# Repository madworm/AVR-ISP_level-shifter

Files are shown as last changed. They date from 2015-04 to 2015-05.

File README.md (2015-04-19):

AVR-ISP_level-shifter
=====================

LAYOUT FILES: Bidirectional level-shifter for old 5V-only AVR-ISP programmers
	      (or for ones that claim to do 3.3V and only offer that on VCC - not on I/O).

---

Before having PC-boards made, please make sure you know about your manufacturer's peculiarities!
Especially drill-sizes and their tolerances may vary too much and give you trouble.

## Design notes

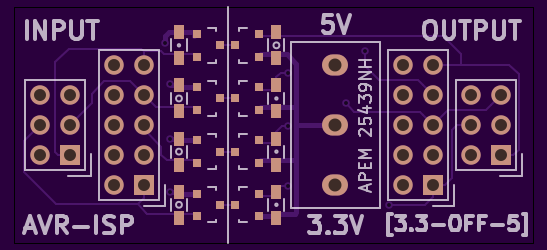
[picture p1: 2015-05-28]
gerber_files/PNGs/AVR-ISP_level-shifter__front_purple.png

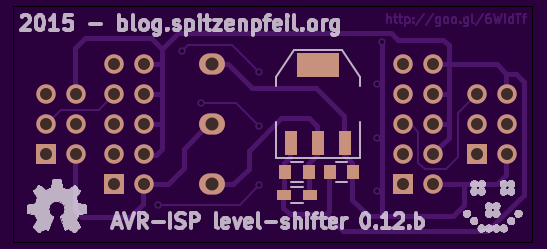
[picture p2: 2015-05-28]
gerber_files/PNGs/AVR-ISP_level-shifter__back_purple.png

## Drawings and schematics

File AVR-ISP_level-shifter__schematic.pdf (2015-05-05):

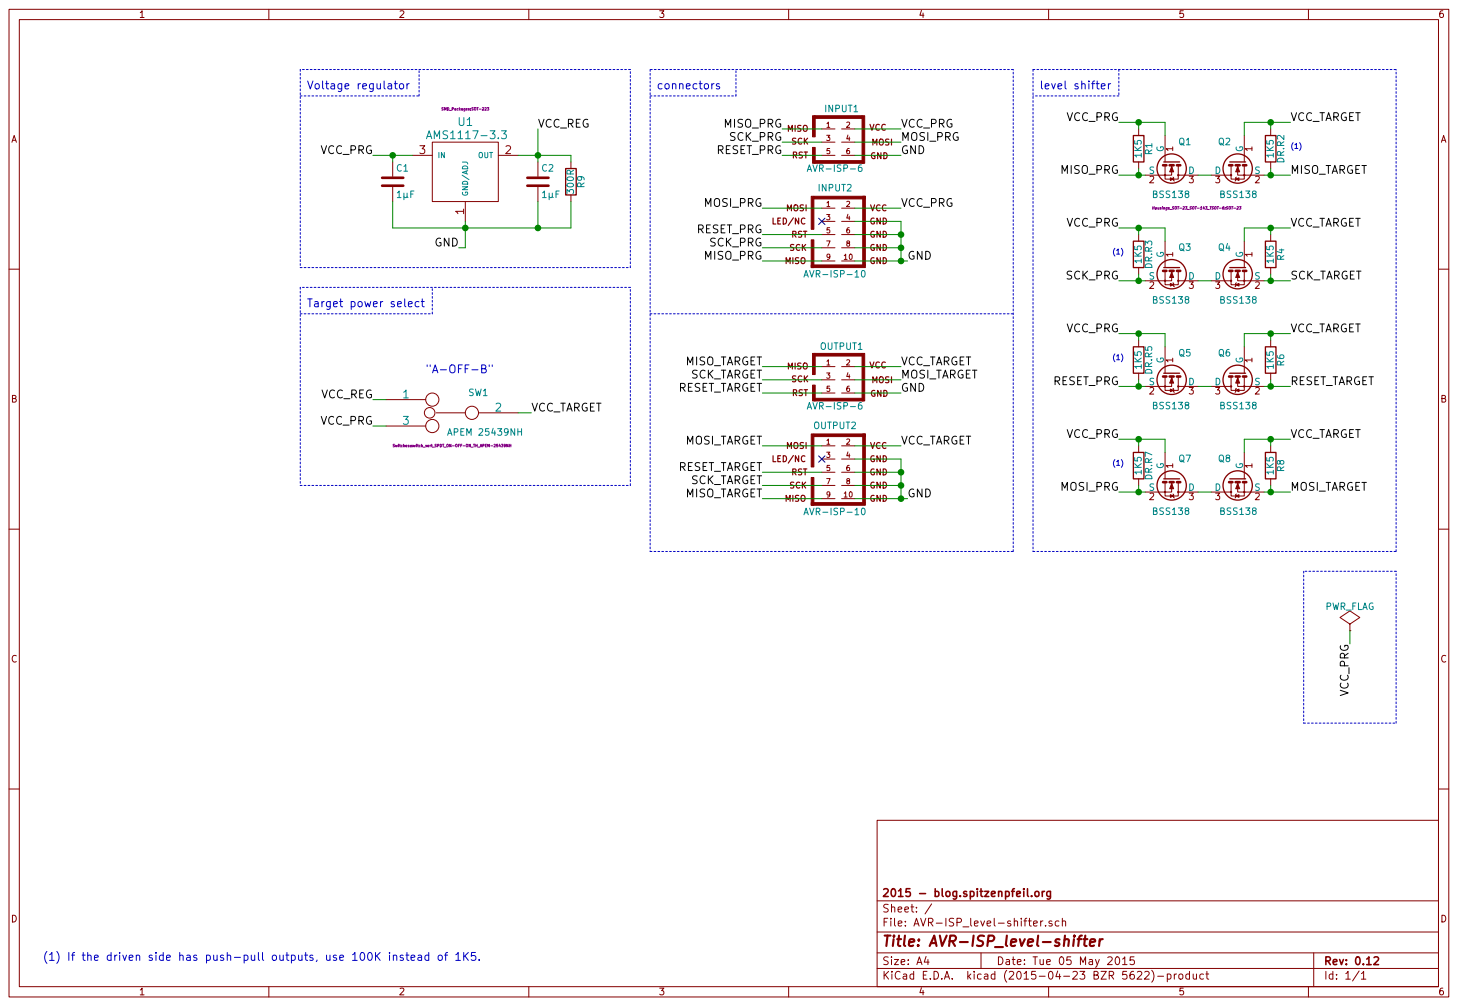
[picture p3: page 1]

File: AVR-ISP_level-shifter.sch Sheet: / 2015 - blog.spitzenpfeil.org GND/ADJ 1

VCC_PRG
VCC GND GND GND

VCC_TARGET

Id: 1/1 Title: AVR-ISP_level-shifter

(1) If the driven side has push-pull outputs, use 100K instead of 1K5.

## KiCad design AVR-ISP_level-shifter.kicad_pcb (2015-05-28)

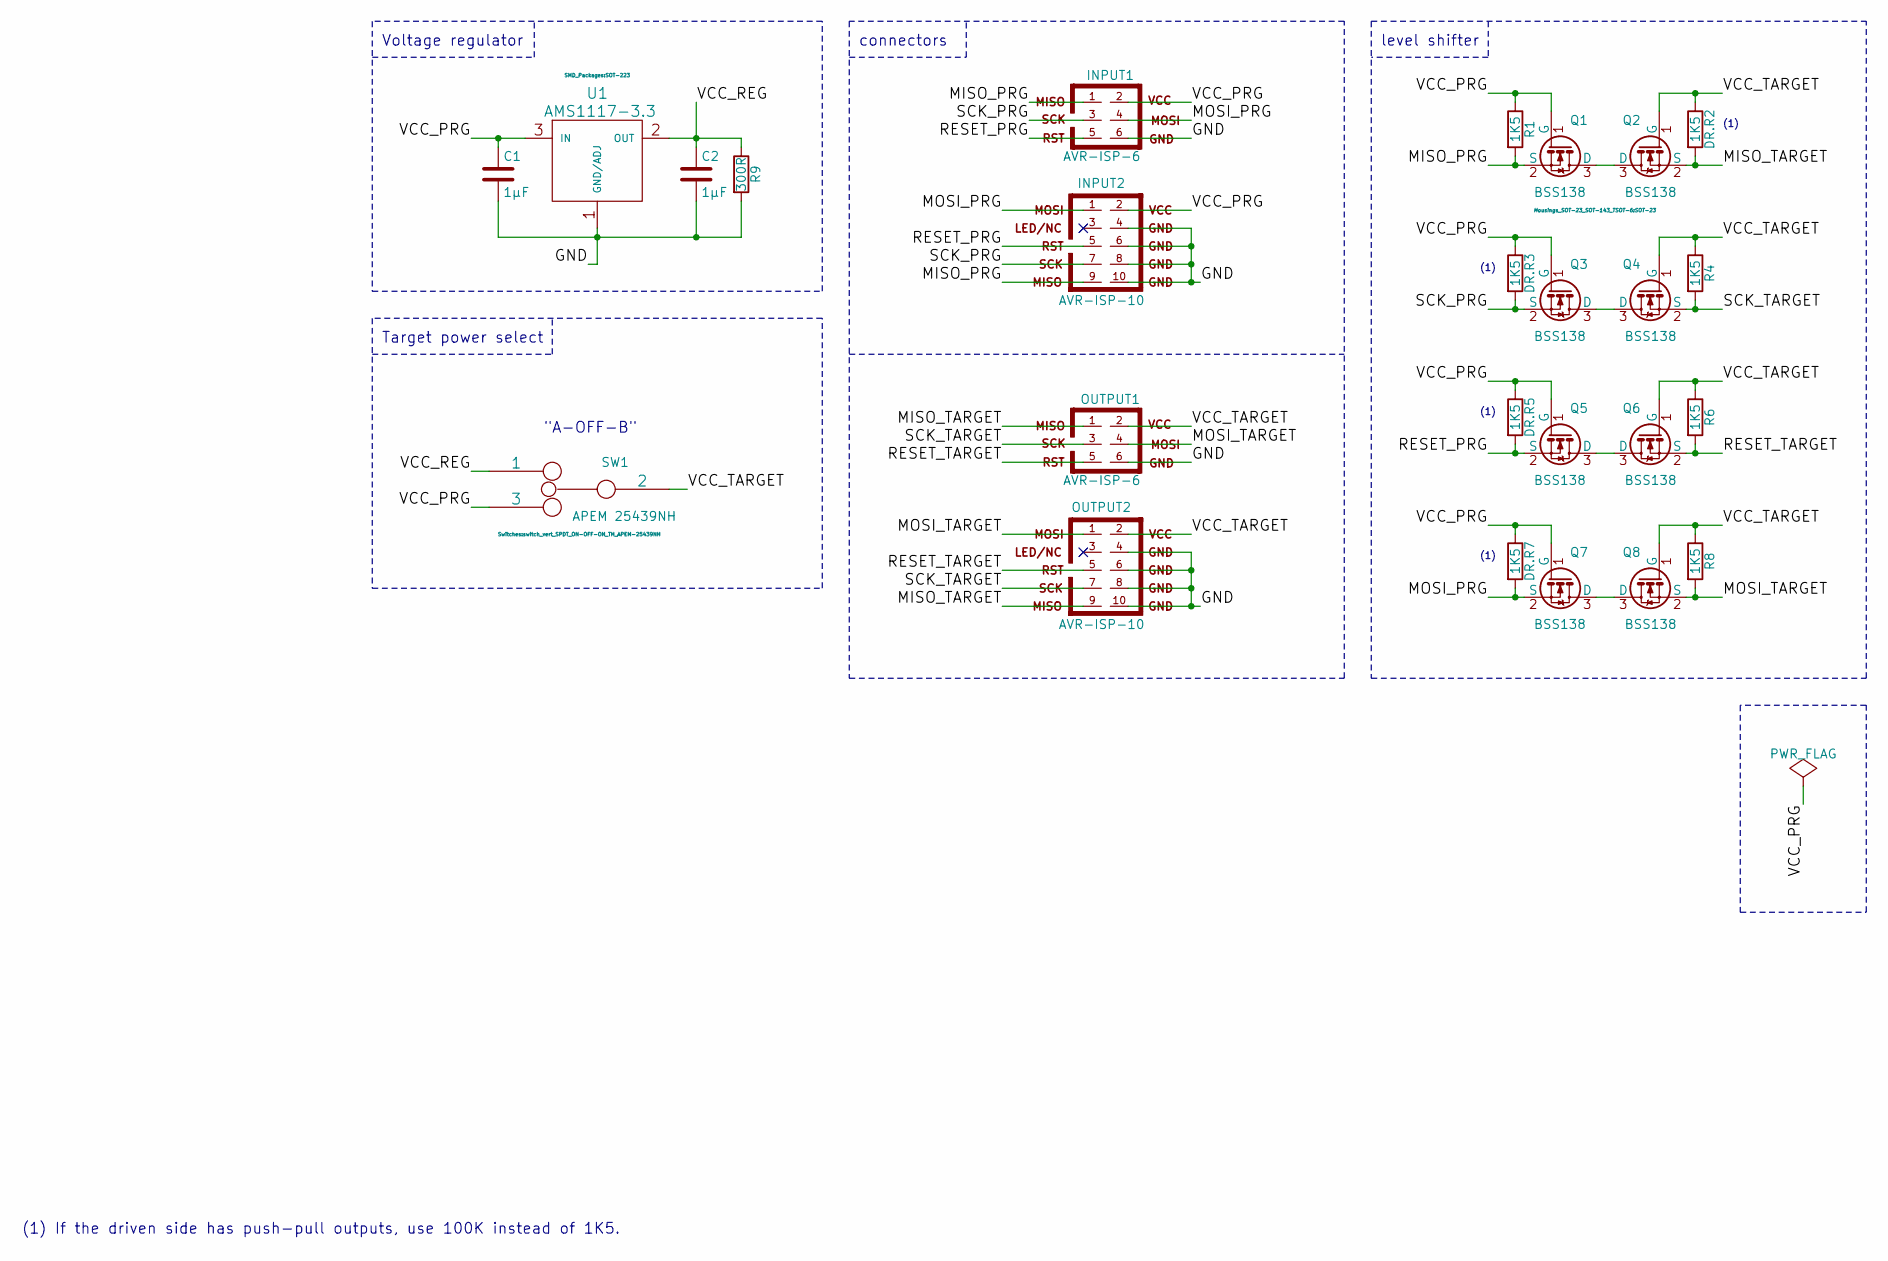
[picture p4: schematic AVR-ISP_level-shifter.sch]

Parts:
C1, C2: 1µF; C_0805
DR.R2, DR.R3, DR.R5, DR.R7: 1K5; R_0603_HandSoldering
INPUT1: AVR-ISP-6; DIL-3
INPUT2: AVR-ISP-10; DIL-5
OUTPUT1: AVR-ISP-6; DIL-3
OUTPUT2: AVR-ISP-10; DIL-5
Q1, Q2, Q3, Q4, Q5, Q6, Q7, Q8: BSS138; SOT-23
R1, R4, R6, R8: 1K5; R_0603_HandSoldering
R9: 300R; R_0603_HandSoldering
SW1: APEM 25439NH; switch_vert_SPDT_ON-OFF-ON_TH_APEM-25439NH
U1: AMS1117-3.3; SOT-223

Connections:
/GND: C1.2, C2.2, INPUT1.6, INPUT2.4, INPUT2.6, INPUT2.8, INPUT2.10, OUTPUT1.6, OUTPUT2.4, OUTPUT2.6, OUTPUT2.8, OUTPUT2.10, R9.2, U1.1 (GND/ADJ)
/MISO_PRG: INPUT1.1, INPUT2.9, Q1.2 (S), R1.2
/MISO_TARGET: DR.R2.2, OUTPUT1.1, OUTPUT2.9, Q2.2 (S)
/MOSI_PRG: DR.R7.2, INPUT1.4, INPUT2.1, Q7.2 (S)
/MOSI_TARGET: OUTPUT1.4, OUTPUT2.1, Q8.2 (S), R8.2
/RESET_PRG: DR.R5.2, INPUT1.5, INPUT2.5, Q5.2 (S)
/RESET_TARGET: OUTPUT1.5, OUTPUT2.5, Q6.2 (S), R6.2
/SCK_PRG: DR.R3.2, INPUT1.3, INPUT2.7, Q3.2 (S)
/SCK_TARGET: OUTPUT1.3, OUTPUT2.7, Q4.2 (S), R4.2
/VCC_PRG: C1.1, DR.R3.1, DR.R5.1, DR.R7.1, INPUT1.2, INPUT2.2, Q1.1 (G), Q3.1 (G), Q5.1 (G), Q7.1 (G), R1.1, SW1.3, U1.3 (IN)
/VCC_REG: C2.1, R9.1, SW1.1, U1.2 (OUT)
/VCC_TARGET: DR.R2.1, OUTPUT1.2, OUTPUT2.2, Q2.1 (G), Q4.1 (G), Q6.1 (G), Q8.1 (G), R4.1, R6.1, R8.1, SW1.2
unnamed: Q1.3 (D), Q2.3 (D)
unnamed: Q3.3 (D), Q4.3 (D)
unnamed: Q5.3 (D), Q6.3 (D)
unnamed: Q7.3 (D), Q8.3 (D)

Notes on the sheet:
"A-OFF-B"
connectors
Voltage regulator
Target power select
(1) If the driven side has push-pull outputs, use 100K instead of 1K5.
level shifter
(1)

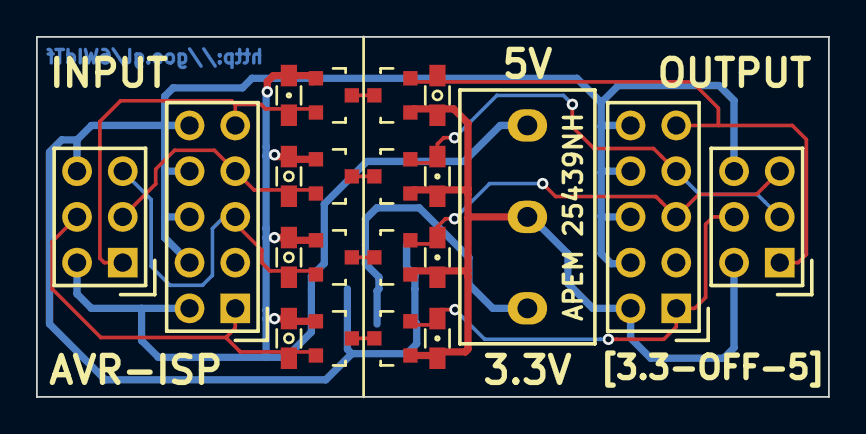
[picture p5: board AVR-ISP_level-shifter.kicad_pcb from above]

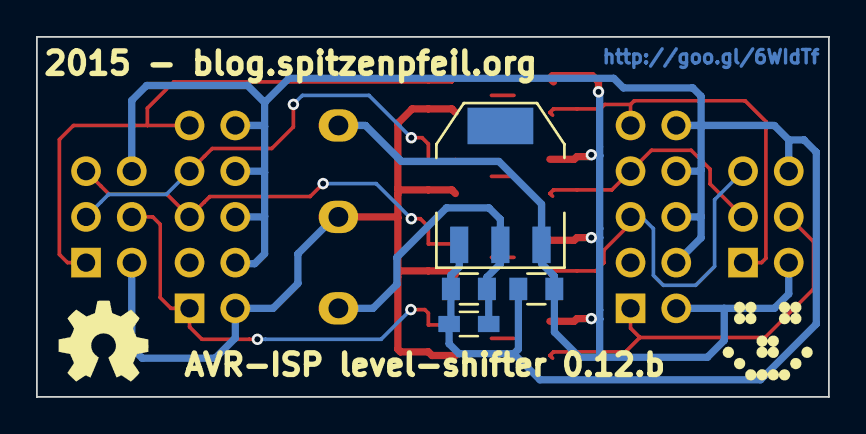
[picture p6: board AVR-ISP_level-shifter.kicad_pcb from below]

Board: 2 copper layers, 44.0 x 20.0 mm, 27 parts (6 on the bottom side), 16 nets.

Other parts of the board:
LOGO1: LED_smile_silkscreen_5mm
LOGO2: OSHW-logo_silkscreen_5mm

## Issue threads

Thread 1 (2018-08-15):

Improvement: Different transistor to allow lower voltages

matthijskooijman, 2018-08-15:
The currently used 2N7000 has a gate threshold of 0.8V - 3.0V, so it might not work on voltages below 3.0V. Using a transistor with a lower gate threshold might allow a wider range of operating voltages.

Perhaps the BSS138 is suitable? It is SMD, but has 1.3V typical and 1.5V max. It is also used in [this similar project](https://github.com/madworm/AVR-ISP_level-shifter).

madworm, 2018-08-20:
The last time I looked, this project used the BSS138 (see the schematic) :-)

matthijskooijman, 2018-08-20:
Heh, I was planning to create these two tickets in my own repo (https://github.com/matthijskooijman/FtdiTranslator) which contains a similar design for an FTDI-compatible serial connector, referring to this repo, but it seemed I messed that up :-P

So, this ticket is completely pointless and can be closed, the other one is apparently a useful suggestion, so I'll leave it open.

madworm, 2018-08-20:
No worries :-)

Closed 2018-08-20.

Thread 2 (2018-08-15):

Improvement: Variable regulator

matthijskooijman, 2018-08-15:
A variable regulator could be added, with a small potmeter to control its voltage?

madworm, 2018-08-20:
Good idea... not time though :-(

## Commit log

2015-04-19 Schematic + footprint assignation might be done.
    [AVR-ISP_level-shifter.sch]
2015-04-19 Changed a few footprints.
    [AVR-ISP_level-shifter.kicad_pcb, AVR-ISP_level-shifter.sch]
2015-04-19 Might be done!
    [AVR-ISP_level-shifter-B_Cu.gbl, AVR-ISP_level-shifter-B_Mask.gbs, AVR-ISP_level-shifter-B_SilkS.gbo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]
2015-04-19 Added shortened URL to github repo to board.
    [AVR-ISP_level-shifter-B_Cu.gbl, AVR-ISP_level-shifter-B_Mask.gbs, AVR-ISP_level-shifter-B_SilkS.gbo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]
2015-04-24 Added comment to schematic + silkscreen tweaks.
    [AVR-ISP_level-shifter.kicad_pcb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]
2015-05-05 Added load resistor (~300R) to pull minimum load current out of 3.3V LDO.
    [AVR-ISP_level-shifter.kicad_pcb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]
2015-05-28 Changed footprints for easier handsoldering + necessary tweaks.
    [AVR-ISP_level-shifter-B_Cu.gbl, AVR-ISP_level-shifter-B_Mask.gbs, AVR-ISP_level-shifter-B_SilkS.gbo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]
